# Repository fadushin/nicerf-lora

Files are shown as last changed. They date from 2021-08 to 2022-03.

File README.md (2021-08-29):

This repository contains [KiCad5](https://www.kicad.org) files for a small (less than 1" square) 2-sided PCB that can be used to integrate a [NiceRF SX127X](https://www.nicerf.com/products/detail/100mw-lora-wireless-transceiver-module-lora1276-915.html) (or equivalent) LoRa transceiver into your maker projects.

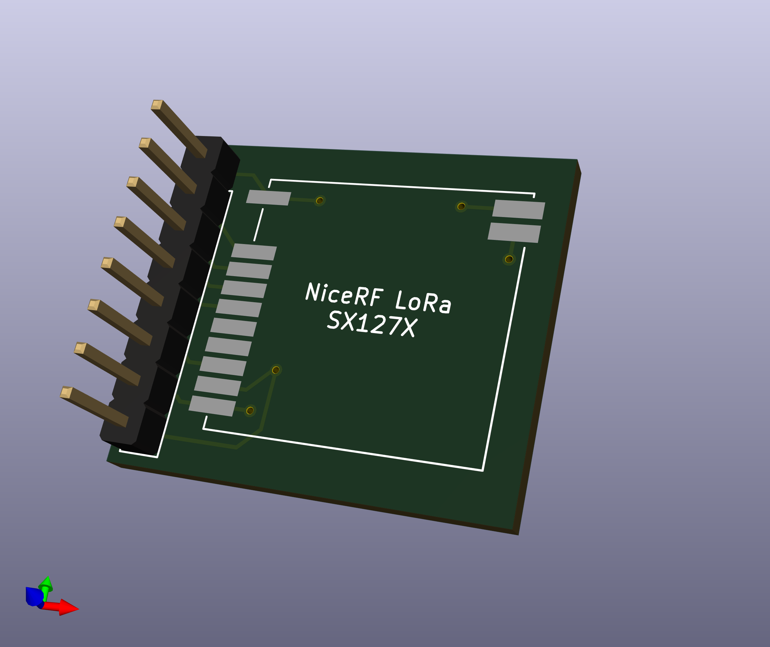
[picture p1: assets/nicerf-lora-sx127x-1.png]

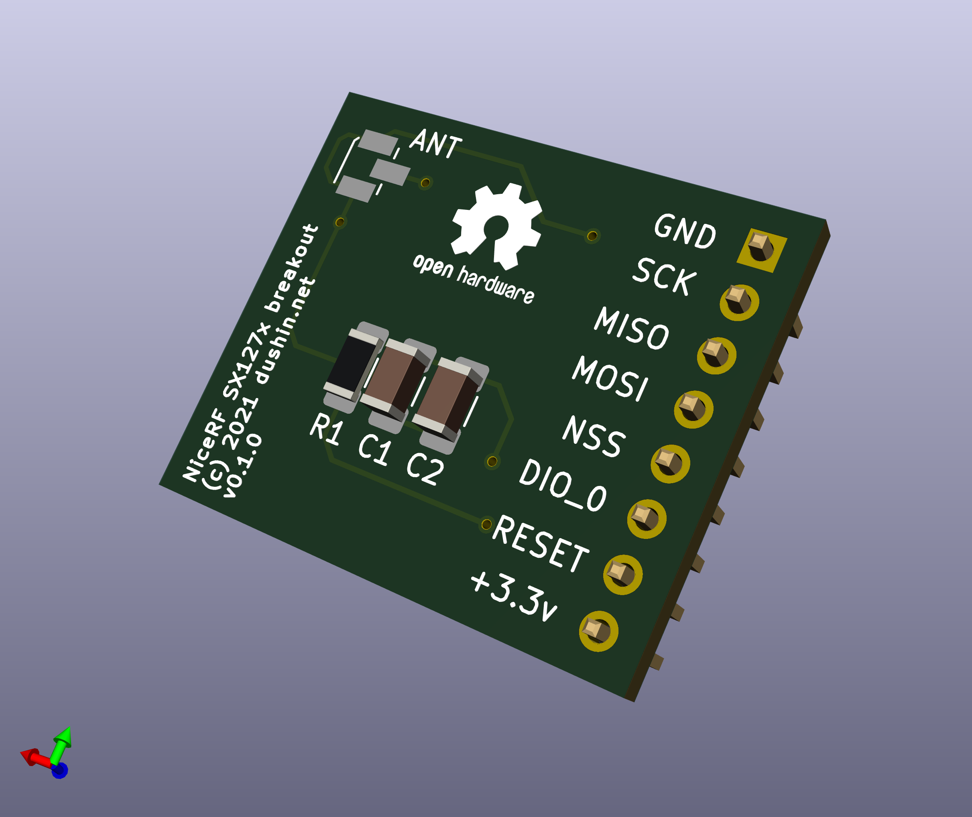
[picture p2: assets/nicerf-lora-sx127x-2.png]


The [NiceRF SX127X](https://www.nicerf.com/products/detail/100mw-lora-wireless-transceiver-module-lora1276-915.html) LoRa transceiver has some desirable properties, such as its small form factor, ability to integrate flexibly with ESP32 projects (unlike some integrated development boards), and it is probably one of the more affordable SX127X boards out there.  In addition, the NiceRF team provides great support for their products.

This PCB adds support for:

* One [NiceRF SX127X](https://www.nicerf.com/products/detail/100mw-lora-wireless-transceiver-module-lora1276-915.html) module
* 2.54mm pins for GND, +3.3v, MOSI, MISO, SCLK, NSS, RESET (optional), and DPIO_0 pins on the NiceRF board, making the board slightly easier to use with standard dupont wires or breadboards;
* A set of pads for a standard IPEX antenna connector;
* A 1206 SMT 10k ohm resistor for the RESET circuit;
* Two 1206 SMT capacitors (optional).

Caveats:

* Currently no support for `DIO_1` and `DIO_2` pins (but could be added easily);
* Only tested on SX1276-915 modules;
* Has not been tested with SWT or VNA meter for antenna circuit leakage or reflection.

This work is licensed under the terms of the BSD License 2.0.  Enjoy!

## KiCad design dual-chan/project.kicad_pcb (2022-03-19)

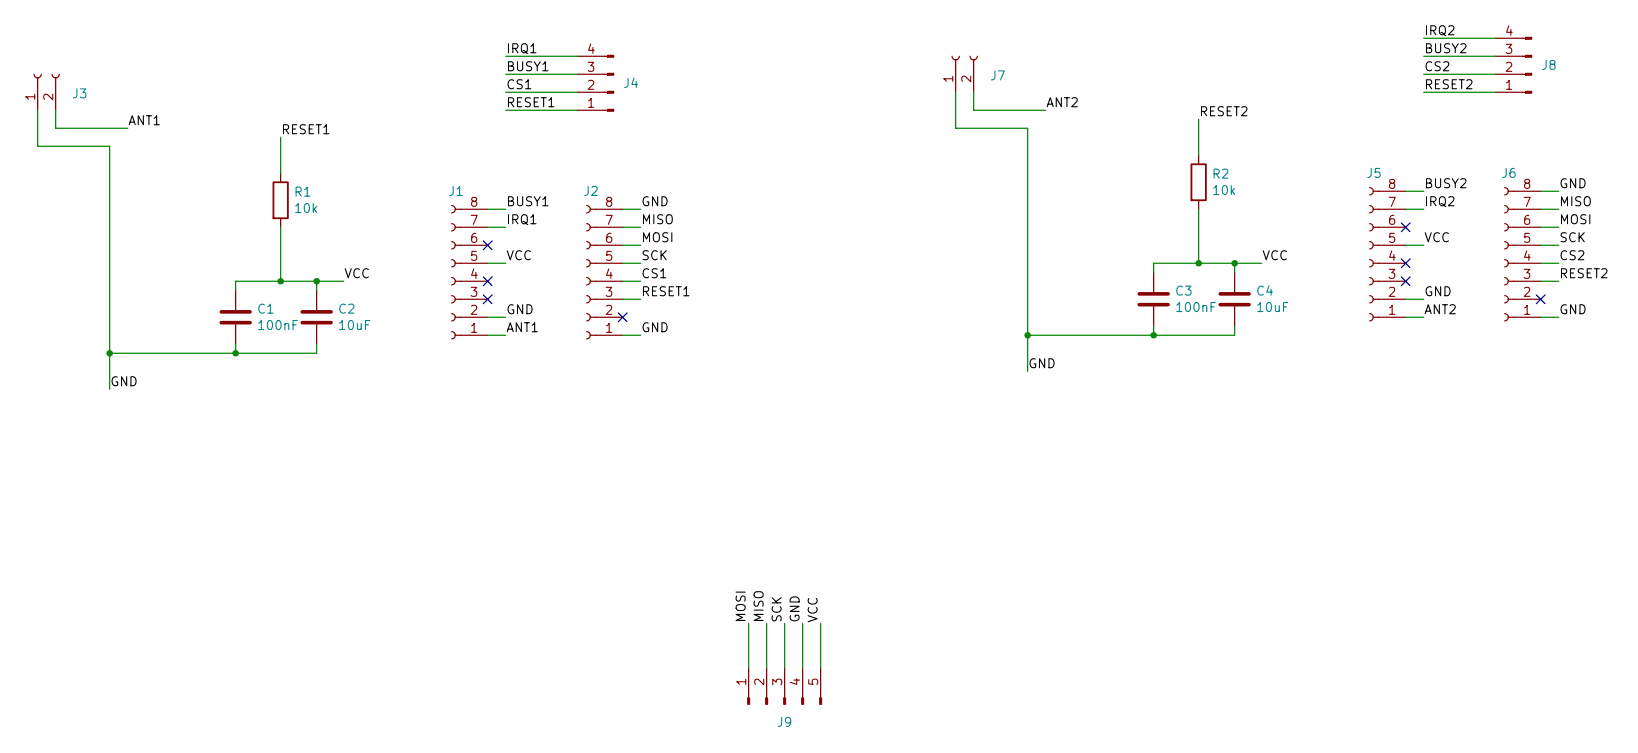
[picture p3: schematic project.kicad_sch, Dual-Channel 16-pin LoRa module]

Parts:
C1, C3: 100nF; C_1206_3216Metric_Pad1.33x1.80mm_HandSolder
C2, C4: 10uF; C_1206_3216Metric_Pad1.33x1.80mm_HandSolder
J1, J2, J5, J6: Conn_01x08_Female; PinSocket_1x08_P2.00mm_Vertical
J3, J7: Conn_01x02_Female; IPEX_Antenna_Connector
J4, J8: Conn_01x04_Male; PinHeader_1x04_P2.54mm_Vertical
J9: Conn_01x05_Male; PinHeader_1x05_P2.54mm_Vertical
R1, R2: 10k; R_1206_3216Metric_Pad1.30x1.75mm_HandSolder

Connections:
/ANT1: J1.1, J3.2
/ANT2: J5.1, J7.2
/BUSY1: J1.8, J4.3
/BUSY2: J5.8, J8.3
/CS1: J2.4, J4.2
/CS2: J6.4, J8.2
/GND: C1.2, C2.2, C3.2, C4.2, J1.2, J2.1, J2.8, J3.1, J5.2, J6.1, J6.8, J7.1, J9.4
/IRQ1: J1.7, J4.4
/IRQ2: J5.7, J8.4
/MISO: J2.7, J6.7, J9.2
/MOSI: J2.6, J6.6, J9.1
/RESET1: J2.3, J4.1, R1.1
/RESET2: J6.3, J8.1, R2.1
/SCK: J2.5, J6.5, J9.3
/VCC: C1.1, C2.1, C3.1, C4.1, J1.5, J5.5, J9.5, R1.2, R2.2

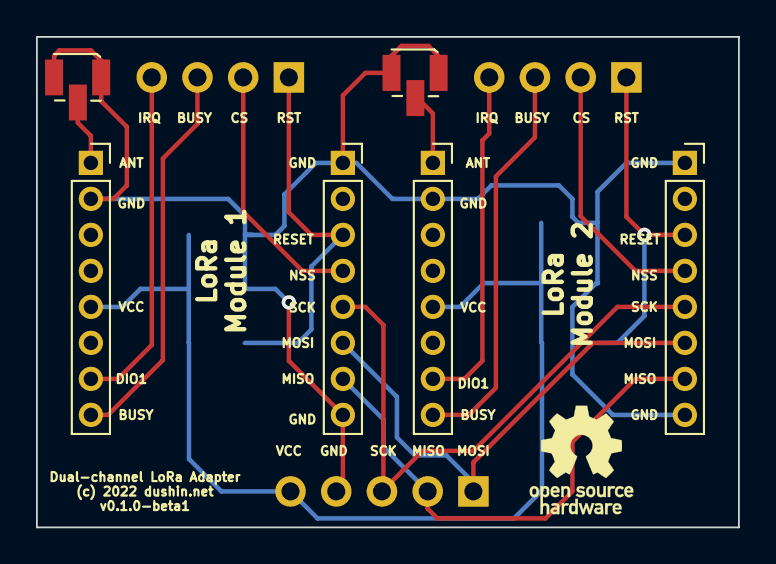
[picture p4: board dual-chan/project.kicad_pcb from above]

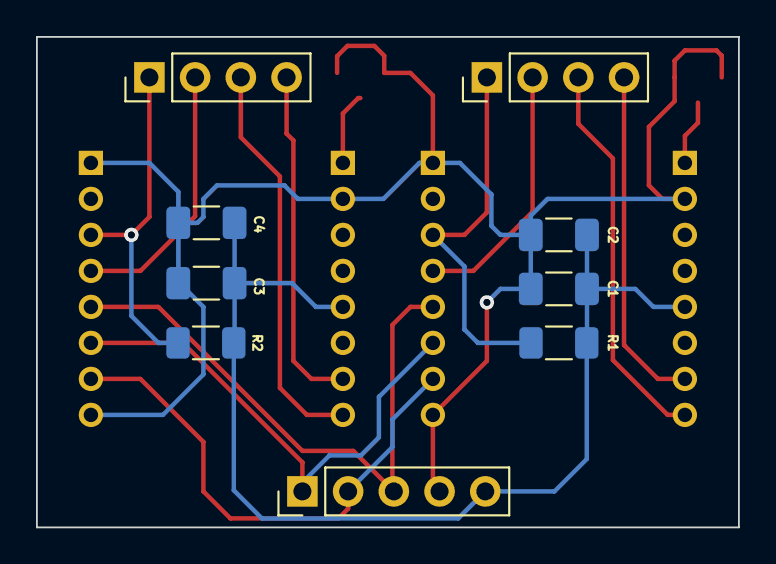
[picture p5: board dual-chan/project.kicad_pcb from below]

Board: 2 copper layers, 39.0 x 27.2 mm, 15 parts (9 on the bottom side), 15 nets.

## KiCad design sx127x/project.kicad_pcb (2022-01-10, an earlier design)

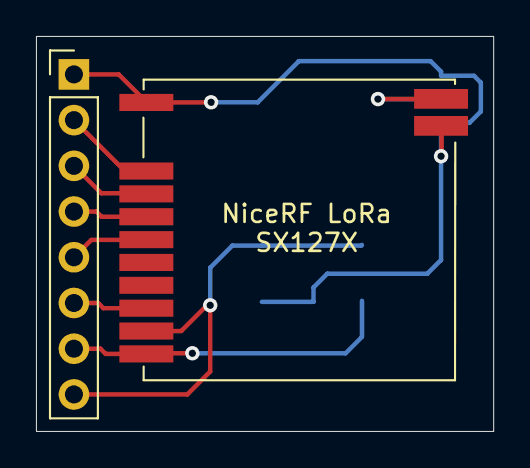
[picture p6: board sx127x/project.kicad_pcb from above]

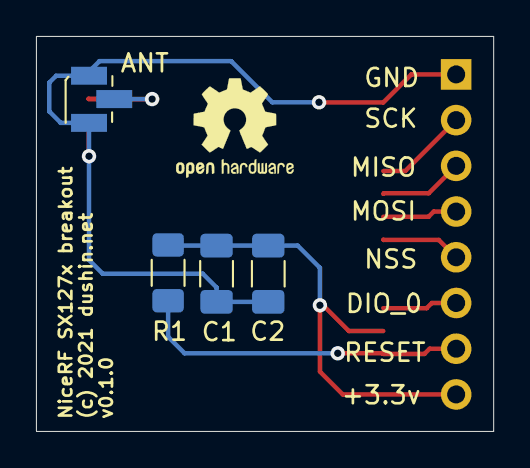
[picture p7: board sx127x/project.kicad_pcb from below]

Board: 2 copper layers, 25.4 x 21.9 mm, 6 parts (4 on the bottom side), 9 nets.

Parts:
C1: 100pF; C_1206_3216Metric_Pad1.33x1.80mm_HandSolder
C2: 102pF; C_1206_3216Metric_Pad1.33x1.80mm_HandSolder
J1: Conn_01x08_Female; PinHeader_1x08_P2.54mm_Vertical
J2: Conn_01x02_Female; IPEX_Antenna_Connector
R1: 10k; R_1206_3216Metric_Pad1.30x1.75mm_HandSolder
U1: NiceRF SX127X; nicerf-lora-sx127x

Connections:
/ANT: J2.2, U1.13
/DIO0: J1.6, U1.10
/GND: C1.2, C2.2, J1.1, J2.1, U1.1, U1.14
/MISO: J1.3, U1.5
/MOSI: J1.4, U1.6
/NSS: J1.5, U1.7
/RESET: J1.7, R1.1, U1.12
/SCK: J1.2, U1.4
/VCC: C1.1, C2.1, J1.8, R1.2, U1.11

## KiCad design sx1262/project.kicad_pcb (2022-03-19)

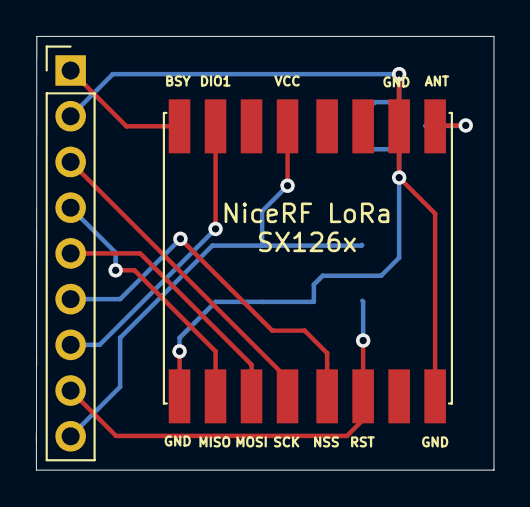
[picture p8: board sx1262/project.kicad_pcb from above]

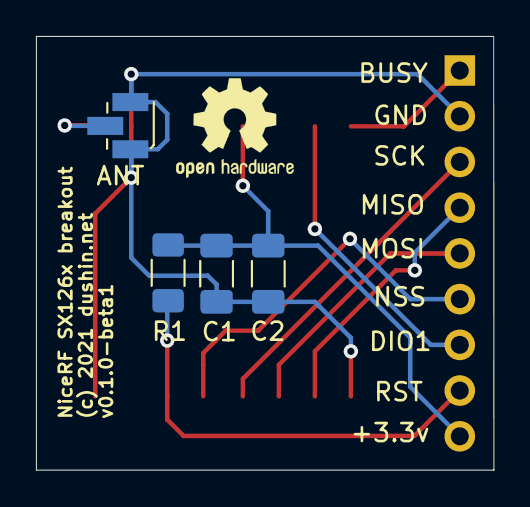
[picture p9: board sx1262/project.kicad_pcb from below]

Board: 2 copper layers, 25.4 x 24.1 mm, 6 parts (4 on the bottom side), 10 nets.

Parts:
C1: 100nF; C_1206_3216Metric_Pad1.33x1.80mm_HandSolder
C2: 10uF; C_1206_3216Metric_Pad1.33x1.80mm_HandSolder
J1: Conn_01x09_Female; PinHeader_1x09_P2.54mm_Vertical
J2: Conn_01x02_Female; IPEX_Antenna_Connector
R1: 10k; R_1206_3216Metric_Pad1.30x1.75mm_HandSolder
U1: nicerf-lora-sx1262

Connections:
/ANT: J2.2, U1.9
/BUSY: J1.1, U1.16
/DIO0: J1.7, U1.15
/GND: C1.2, C2.2, J1.2, J2.1, U1.1, U1.8, U1.10
/MISO: J1.4, U1.2
/MOSI: J1.5, U1.3
/NSS: J1.6, U1.5
/RESET: J1.8, R1.1, U1.6
/SCK: J1.3, U1.4
/VCC: C1.1, C2.1, J1.9, R1.2, U1.13

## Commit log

2021-08-29 NiceRF SX127X breakout board
    [nicerf-lora-sx127x.kicad_pcb, nicerf-lora-sx127x.sch]
2022-01-10 Moved sx127x files into its own directory.
    [project.kicad_pcb, project.sch]
2022-01-10 Added Kicad files for SX1262
    [project.kicad_pcb, project.sch]
2022-03-19 Added dual-channel RF adapter
    [project.kicad_pcb, project.kicad_sch, project.sch]

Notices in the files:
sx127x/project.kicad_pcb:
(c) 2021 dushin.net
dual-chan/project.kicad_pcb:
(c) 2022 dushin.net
